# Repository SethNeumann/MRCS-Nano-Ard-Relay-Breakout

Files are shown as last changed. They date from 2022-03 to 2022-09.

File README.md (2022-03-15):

# REPO NAME: MRCS-Nano-Ard-Relay-Breakout

## License: Creative Commons Attribution-NonCommercial-ShareAlike

A client wanted a simple automation controller to turn many sound animation units on and off
more less randomly.  He had the modules and gotten as far as turning them on and off with Arduino
relays. I discussed the project with contributor Jon Schmidt and created a sketch.  The board simply maps 
the Nanos D2-D3 and A0-A3 to male header pins with power and +5 in the appropriate places.  All you need to do 
make up cables with Dupont type cables (0.100 available for Pololu and many others) in the appropriate sizes.

Power is from a 5V wall wart which powers the Nano and associated relays

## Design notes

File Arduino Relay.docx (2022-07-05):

Arduino Relay

This is another in a series of Arduino Nano breakout boards which feature a Nano, some supporting circuitry and connectors intended to solve a particular task. In this case we needed to control a group of “Arduino Relays” which in turn controlled a group of Sound Animation modules. The board has a socket for the Nano and 4 sets of male headers which correspond to the +5, GND and inputs for various configurations of Arduino Relay. Power filtering is provided as are a choice of 2.1 mm barrel jack and 3.5mm screw terminals.

- 2 x 10 position 0.100 headers for either 2 8 position or 1 16 position Arduino Relay (D2-D13 + A0-A3) Each header has Ground, +5 and 8 outputs
- 4 x 6 position 0.100 headers for 4 position Arduino Relays (D2-D13 + A0-A3)
- 4 x 4 position 0.100 headers for 2 position Arduino Relays
- 4 x 3 position 0.100 headers for single Arduino Relays (note the pattern is different for the singlets)
- Barrel Jack for 5VDC (1A recommended) as well as 2 pairs of +5/GND on the 3.5 mm screw terminal, you can use either or use the screw terminal to distribute power to adjacent modules
- 0.100” Pads are provided for the unused Arduino i/o pins and +5 and Ground

Arduino Pin | 8/16 | 4 | 2 | 1
D2 | 0 | 0 | 0
D3
D4 | | | 1
D5
D6 | | 1 | 2
D7
D8 | | | 3
D9
D10 | 1 | 2 | | 0
D11 | | | | 1
D12 | | | | 2
D13 | | | | 3
A0 | | 3
A1
A2
A3

Note that there is no magic about Arduino Relays: this board can be used to consolidate i/o and power to any type of device you like and there are many sensors and output devices compatible with Arduinos that may use this cabling.

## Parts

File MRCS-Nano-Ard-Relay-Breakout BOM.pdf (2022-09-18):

Qty | Value | Device | Package
4 | CONNECTOR-M04LOCK | 1X04_LOCK
4 | CONNECTOR-M06LOCK | 1X06_LOCK
| 1 .1 @ 25V | CAPPTH2 | C-PTH-0.100
| 1 470 uF @ 16V | CAP-POLPTH-3.5MM | E3.5-10
| 1 5V PWR | CONNECTOR-DC-POWER-RA | DCJ0202
| 1 5V PWR | CONNECTOR-M04SCREW_LOCK | SCREWTERMINAL-3.5MM-4_LOCK
| 4 CONNECTOR-M03MOLEX-254-LOCK | CONNECTOR-M03MOLEX-254-LOCK | MOLEX-1X3_LOCK
| 2 CONNECTOR-M102MM | CONNECTOR-M102MM | 1X10-2MM
| 1 NANO | NANO | NANO
| 1 Unused I/O | CONNECTOR-M08LOCK | 1X08_LOCK
| 2 15 pin | 0.100 x 15 female header
| 1 Arduino Relay Breakout PCB | Arduino Relay Breakout PCB | 69x100

Parts | Description
D3-2, D5-4, D7-6, D9-8 | Header 4
A3-0, D5-2, D9-6, D13-10 Header 6 Standard 6-pin 0.1 header" C2
C1
J1 | DC POWER JACK
CON1 | Header 4
D10, D11, D12, D13
D2-D9, D10-A3 | Header 10
U$1 | Arduino Nano
J2 | Header 8
N1, N2 | Nano Header
| Circuit Board

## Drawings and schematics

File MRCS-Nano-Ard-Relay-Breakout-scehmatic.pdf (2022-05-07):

A

1 | 2 | 3 | 4 | 5 | 6

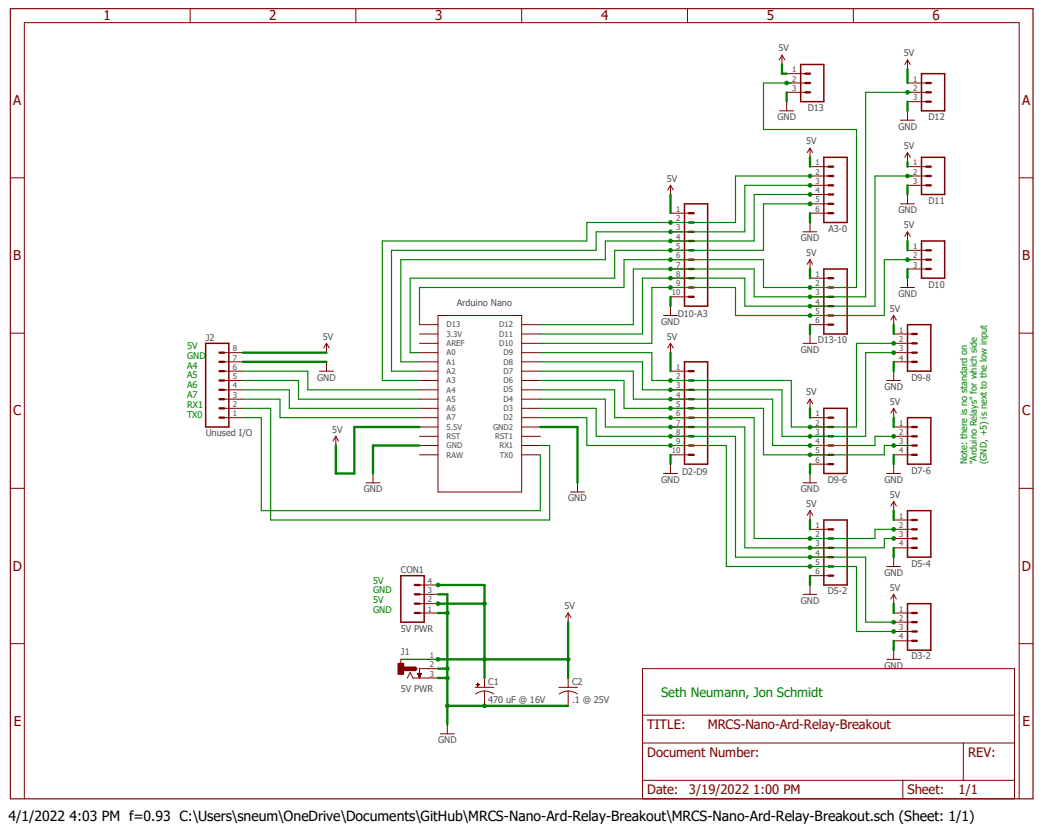
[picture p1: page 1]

Seth Neumann, Jon Schmidt

MRCS-Nano-Ard-Relay-Breakout

Document Number: | REV:

Date: 3/19/2022 1:00 PM | Sheet: 1/1

4/1/2022 4:03 PM f=0.93 C:\Users\sneum\OneDrive\Documents\GitHub\MRCS-Nano-Ard-Relay-Breakout\MRCS-Nano-Ard-Relay-Breakout.sch (Sheet: 1/1)

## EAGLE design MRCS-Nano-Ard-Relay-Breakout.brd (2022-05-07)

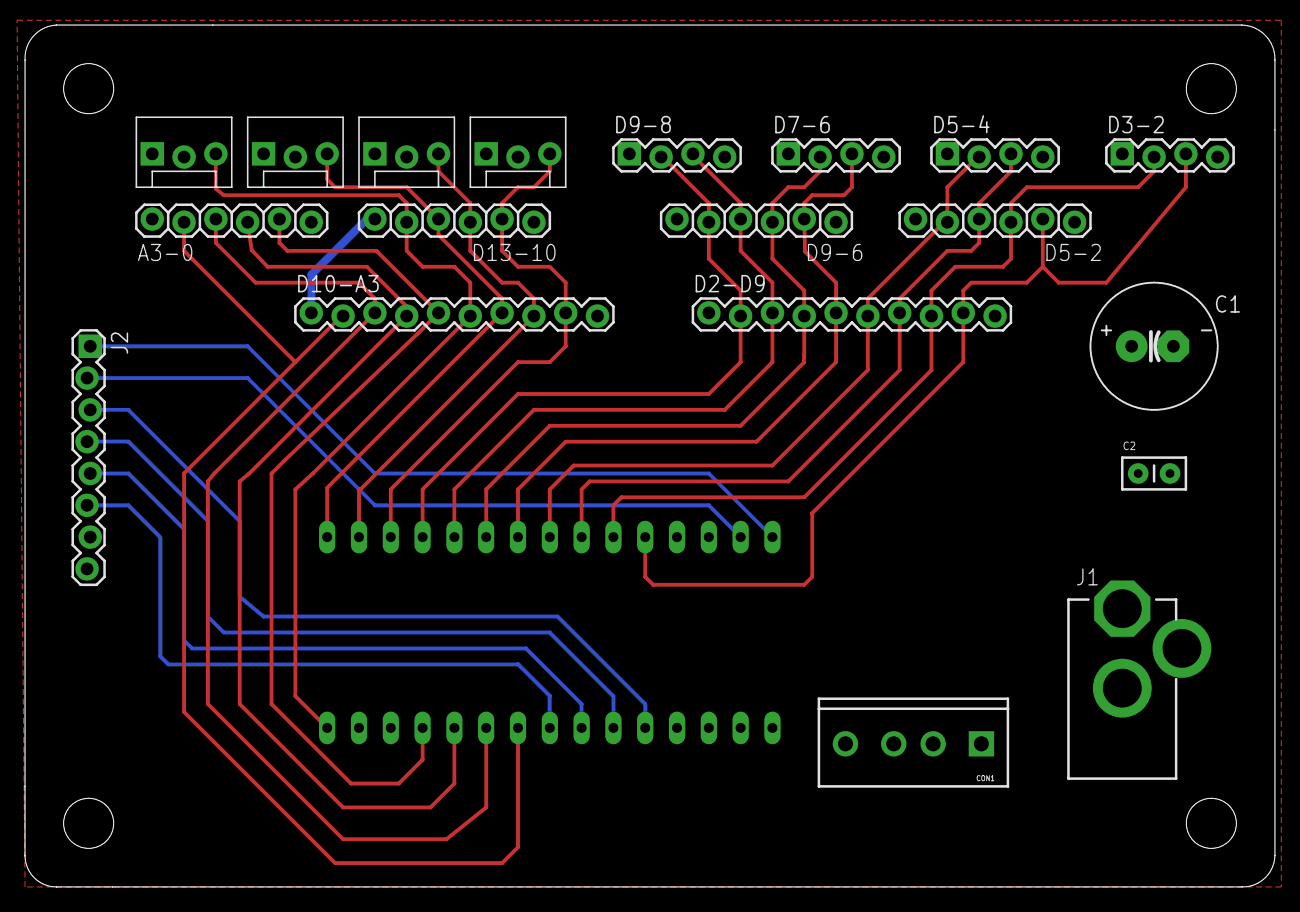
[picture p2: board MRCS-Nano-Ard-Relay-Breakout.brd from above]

Board: 2 copper layers, 99.8 x 68.8 mm, 24 parts (0 on the bottom side), 24 nets.

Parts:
A3-0: 1X06_LOCK
C1: 470 uF @ 16V; E3.5-10
C2: .1 @ 25V; C-PTH-0.100
CON1: 5V PWR; SCREWTERMINAL-3.5MM-4_LOCK
D2-D9, D10-A3: CONNECTOR-M10LOCK; 1X10_LOCK
D3-2, D5-4, D7-6, D9-8: 1X04_LOCK
D5-2, D9-6, D13-10: 1X06_LOCK
D10, D11, D12, D13: CONNECTOR-M03MOLEX-254-LOCK; MOLEX-1X3_LOCK
J1: 5V PWR; DCJ0202
J2: Unused I/O; 1X08_LOCK
U$1: NANO
U$2: CA-PROP65WARNING
U$3: MRCSLOGOTOP
U$4: MRCSLOGOBTM
U$10: BOARD-DINRAIL-2.7IN

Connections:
5V: A3-0.1, C1.+, C2.1, CON1.2, CON1.4, D2-D9.1, D3-2.1, D5-2.1, D5-4.1, D7-6.1, D9-6.1, D9-8.1, D10.1, D10-A3.1, D11.1, D12.1, D13.1, D13-10.1, J1.1, J2.8, U$1.5V
A4: J2.6, U$1.A4
A5: J2.5, U$1.A5
A6: J2.4, U$1.A6
A7: J2.3, U$1.A7
GND: A3-0.6, C1.-, C2.2, CON1.1, CON1.3, D2-D9.10, D3-2.4, D5-2.6, D5-4.4, D7-6.4, D9-6.6, D9-8.4, D10.2, D10-A3.10, D11.2, D12.2, D13.2, D13-10.6, J1.2, J1.3, J2.7, U$1.GND, U$1.GND1
unnamed: D2-D9.9, D3-2.3, D5-2.5, U$1.D2
unnamed: D2-D9.8, D3-2.2, D5-2.4, U$1.D3
unnamed: D2-D9.5, D7-6.3, D9-6.5, U$1.D6
unnamed: D2-D9.4, D7-6.2, D9-6.4, U$1.D7
unnamed: D2-D9.3, D9-6.3, D9-8.3, U$1.D8
unnamed: D2-D9.2, D9-6.2, D9-8.2, U$1.D9
unnamed: D10.3, D10-A3.9, D13-10.5, U$1.D10
unnamed: D10-A3.8, D11.3, D13-10.4, U$1.D11
unnamed: D10-A3.7, D12.3, D13-10.3, U$1.D12
unnamed: D10-A3.6, D13.3, D13-10.2, U$1.D13
unnamed: A3-0.5, D10-A3.5, U$1.A0
unnamed: A3-0.4, D10-A3.4, U$1.A1
unnamed: A3-0.3, D10-A3.3, U$1.A2
unnamed: A3-0.2, D10-A3.2, U$1.A3
unnamed: D2-D9.7, D5-2.3, D5-4.3, U$1.D4
unnamed: D2-D9.6, D5-2.2, D5-4.2, U$1.D5
RX1: J2.2, U$1.RX1
TX0: J2.1, U$1.TX0

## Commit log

2022-03-15 setting up repository
    copied in a version of the Nano-Grade-Xing controller to start
    [EagleTemplate-new.brd, EagleTemplate-new.sch, MRCS-Nano-Ard-Relay-Breakout.brd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]
2022-03-15 minor label changes after design review
    [MRCS-Nano-Ard-Relay-Breakout.sch]
2022-03-19 files as sent to jlcpcb for 1st run
    completion of design
    [MRCS-Nano-Ard-Relay-Breakout.brd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]
2022-03-30 reflects first board
2022-05-07 fixed connectors 8 and 16 position Arduino Relays
    accidently selected 2mm rather than 2.54mm (0.100) connectors. Fixed positions of the singlets (different pattern of course).
    [MRCS-Nano-Ard-Relay-Breakout.brd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]
2022-07-05 work files
    [MRCS-Nano-Ard-Relay-Breakout.sch]
2022-09-18 clean up of old files
    remove old files
    [MRCS-Nano-Ard-Relay-Breakout.csv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]
2022-09-18 Create MRCS-Nano-Ard-Relay-Breakout BOM.pdf
    Bill of Materials

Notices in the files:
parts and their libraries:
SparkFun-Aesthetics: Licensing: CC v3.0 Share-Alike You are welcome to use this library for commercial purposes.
